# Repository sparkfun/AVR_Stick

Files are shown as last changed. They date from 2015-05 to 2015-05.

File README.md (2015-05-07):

SparkFun AVR Stick
========================================

SparkFun AVR Stick

[*SparkFun AVR Stick (DEV-09147)*](https://www.sparkfun.com/products/9147)

 The SparkFun AVR Stick is a simple data logging device that instantiates itself as an HID keyboard and reports the voltages, along with a ‘timestamp,’ from two pins on an ATtiny85.
 
Repository Contents
-------------------

* **/Firmware** - Example code 
* **/Hardware** - Eagle design files (.brd, .sch)
* **/Production** - Production panel files (.brd)

Documentation
--------------
* **[SparkFun Fritzing repo](https://github.com/sparkfun/Fritzing_Parts)** - Fritzing diagrams for SparkFun products.
* **[SparkFun 3D Model repo](https://github.com/sparkfun/3D_Models)** - 3D models of SparkFun products. 

License Information
-------------------
This product is _**open source**_! 

The **hardware** is released under [Creative Commons ShareAlike 4.0 International](https://creativecommons.org/licenses/by-sa/4.0/).

Please use, reuse, and modify these files as you see fit. Please maintain attribution to SparkFun Electronics and release anything derivative under the same license.

Distributed as-is; no warranty is given.

- Your friends at SparkFun.

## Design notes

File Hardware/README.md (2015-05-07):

SparkFun <PRODUCT NAME> Design Files
=====================================

The .sch and .brd files hare are Eagle CAD schematic and PCB design files from SparkFun Electronics.
A freeware version of Eagle can be found [here](http://www.cadsoftusa.com/download-eagle/freeware/). 

License
---------
This product is open source! 
The hardware is released under [Creative Commons ShareAlike 4.0 International](https://creativecommons.org/licenses/by-sa/4.0/).

Please use, reuse, and modify these files as you see fit. Please maintain attribution to SparkFun Electronics and release anything derivative under the same license.

Distributed as-is; no warranty is given.

- Your friends at SparkFun.

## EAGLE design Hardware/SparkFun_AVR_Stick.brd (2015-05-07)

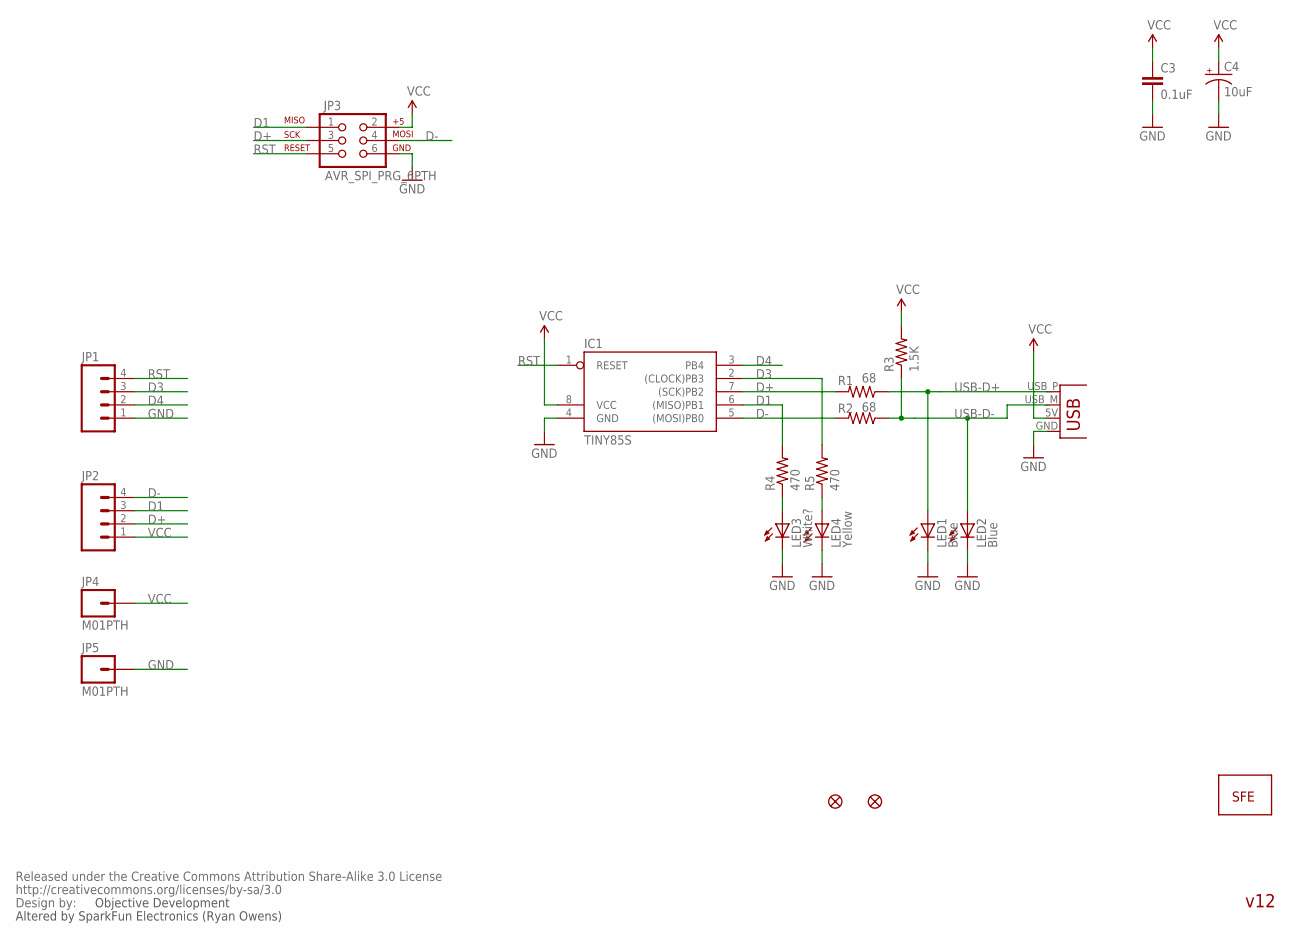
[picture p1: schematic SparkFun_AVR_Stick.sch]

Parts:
C3: 0.1uF; 0402-CAP
C4: 10uF; EIA3216
IC1: TINY85S; SOIC8
JP1, JP2: M04PTH; 1X04
JP3: AVR_SPI_PRG_6PTH; 2X3
JP4, JP5: M01PTH; 1X01
LED1, LED2: Blue; LED-0603
LED3: White?; LED-0603
LED4: Yellow; LED-0603
R1, R2: 68; 0402-RES
R3: 1.5K; 0402-RES
R4, R5: 470; 0402-RES
U$1: LOGO-SFESK; SFE-LOGO-FLAME
U$2, U$3: FIDUCIAL1X2; FIDUCIAL-1X2
U$4: CREATIVE_COMMONS
X1: USBPCB; USB-A-PCB

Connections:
D1: IC1.6 ((MISO)PB1), JP2.3, JP3.1, R4.2
D3: IC1.2 ((CLOCK)PB3), JP1.3, R5.2
D4: IC1.3 (PB4), JP1.2
D+: IC1.7 ((SCK)PB2), JP2.2, JP3.3, R1.2
D-: IC1.5 ((MOSI)PB0), JP2.4, JP3.4, R2.2
GND: C3.2, C4.C (-), IC1.4 (GND), JP1.1, JP3.6, JP5.1, LED1.C, LED2.C, LED3.C, LED4.C, X1.GND
unnamed: LED3.A, R4.1
unnamed: LED4.A, R5.1
RST: IC1.1 (RESET), JP1.4, JP3.5
USB-D+: LED1.A, R1.1, X1.USB_P (D+)
USB-D-: LED2.A, R2.1, R3.1, X1.USB_M (D-)
VCC: C3.1, C4.A (+), IC1.8 (VCC), JP2.1, JP3.2, JP4.1, R3.2, X1.5V (VBUS)

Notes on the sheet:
Objective Development
Altered by SparkFun Electronics (Ryan Owens)
v12

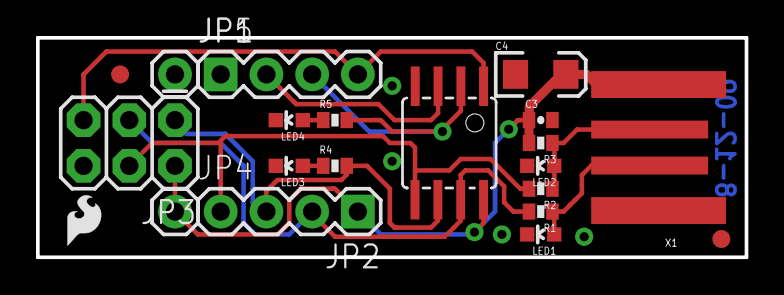
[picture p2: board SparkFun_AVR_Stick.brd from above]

Board: 2 copper layers, 39.4 x 12.2 mm, 22 parts (0 on the bottom side), 12 nets.

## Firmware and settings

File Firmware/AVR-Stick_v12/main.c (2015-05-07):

/* Name: main.c
 * Project: Datalogger based on AVR USB driver
 * Original Author: Christian Starkjohann
 * Edited by Ryan Owens (SparkFun Electronics)
 * Creation Date: 2006-04-23
 * Edited 2009-06-30
 * Tabsize: 4
 * Copyright: (c) 2006 by OBJECTIVE DEVELOPMENT Software GmbH
 * License: Proprietary, free under certain conditions. See Documentation.
 * This Revision: $Id: main.c 537 2008-02-28 21:13:01Z cs $
 */

#include <avr/io.h>
#include <avr/wdt.h>
#include <avr/eeprom.h>
#include <avr/interrupt.h>
#include <avr/pgmspace.h>
#include <util/delay.h>

#include "usbdrv.h"
#include "oddebug.h"

/*
Pin assignment:
PB3 = analog input (ADC3)
PB4 = analog input (ADC2) - Can alternately be used as an LED output.
PB1 = LED output

PB0, PB2 = USB data lines
*/

#define WHITE_LED 3
#define YELLOW_LED 1


#define UTIL_BIN4(x)        (uchar)((0##x & 01000)/64 + (0##x & 0100)/16 + (0##x & 010)/4 + (0##x & 1))
#define UTIL_BIN8(hi, lo)   (uchar)(UTIL_BIN4(hi) * 16 + UTIL_BIN4(lo))

#define sbi(var, mask)   ((var) |= (uint8_t)(1 << mask))
#define cbi(var, mask)   ((var) &= (uint8_t)~(1 << mask))

#ifndef NULL
#define NULL    ((void *)0)
#endif

/* ------------------------------------------------------------------------- */

static uchar    reportBuffer[2];    /* buffer for HID reports */
static uchar    idleRate;           /* in 4 ms units */

static uchar    adcPending;
static uchar	currentAdcChannel=2;
static unsigned int		sampleNum=0;

static uchar    valueBuffer[16];
static uchar    *nextDigit;

/* ------------------------------------------------------------------------- */

PROGMEM char usbHidReportDescriptor[USB_CFG_HID_REPORT_DESCRIPTOR_LENGTH] = { /* USB report descriptor */
    0x05, 0x01,                    // USAGE_PAGE (Generic Desktop)
    0x09, 0x06,                    // USAGE (Keyboard)
    0xa1, 0x01,                    // COLLECTION (Application)
    0x05, 0x07,                    //   USAGE_PAGE (Keyboard)
    0x19, 0xe0,                    //   USAGE_MINIMUM (Keyboard LeftControl)
    0x29, 0xe7,                    //   USAGE_MAXIMUM (Keyboard Right GUI)
    0x15, 0x00,                    //   LOGICAL_MINIMUM (0)
    0x25, 0x01,                    //   LOGICAL_MAXIMUM (1)
    0x75, 0x01,                    //   REPORT_SIZE (1)
    0x95, 0x08,                    //   REPORT_COUNT (8)
    0x81, 0x02,                    //   INPUT (Data,Var,Abs)
    0x95, 0x01,                    //   REPORT_COUNT (1)
    0x75, 0x08,                    //   REPORT_SIZE (8)
    0x25, 0x65,                    //   LOGICAL_MAXIMUM (101)
    0x19, 0x00,                    //   USAGE_MINIMUM (Reserved (no event indicated))
    0x29, 0x65,                    //   USAGE_MAXIMUM (Keyboard Application)
    0x81, 0x00,                    //   INPUT (Data,Ary,Abs)
    0xc0                           // END_COLLECTION
};
/* We use a simplifed keyboard report descriptor which does not support the
 * boot protocol. We don't allow setting status LEDs and we only allow one
 * simultaneous key press (except modifiers). We can therefore use short
 * 2 byte input reports.
 * The report descriptor has been created with usb.org's "HID Descriptor Tool"
 * which can be downloaded from http://www.usb.org/developers/hidpage/.
 * Redundant entries (such as LOGICAL_MINIMUM and USAGE_PAGE) have been omitted
 * for the second INPUT item.
 */

/* Keyboard usage values, see usb.org's HID-usage-tables document, chapter
 * 10 Keyboard/Keypad Page for more codes.
 */
#define MOD_CONTROL_LEFT    (1<<0)
#define MOD_SHIFT_LEFT      (1<<1)
#define MOD_ALT_LEFT        (1<<2)
#define MOD_GUI_LEFT        (1<<3)
#define MOD_CONTROL_RIGHT   (1<<4)
#define MOD_SHIFT_RIGHT     (1<<5)
#define MOD_ALT_RIGHT       (1<<6)
#define MOD_GUI_RIGHT       (1<<7)

#define KEY_1       30
#define KEY_2       31
#define KEY_3       32
#define KEY_4       33
#define KEY_5       34
#define KEY_6       35
#define KEY_7       36
#define KEY_8       37
#define KEY_9       38
#define KEY_0       39
#define KEY_RETURN  40
#define KEY_TAB		43
#define KEY_A		4
#define KEY_B		5
#define KEY_C		6
#define KEY_D		7
#define KEY_E		8
#define KEY_F		9

/* ------------------------------------------------------------------------- */

static void buildReport(void)
{
uchar   key = 0;

    if(nextDigit != NULL){
        key = *nextDigit;
    }
    reportBuffer[0] = 0;    /* no modifiers */
    reportBuffer[1] = key;
}

/* ------------------------------------------------------------------------- */
static void changeAdcChannel(void)
{
	if(currentAdcChannel==3){
		currentAdcChannel=2;
		ADMUX = UTIL_BIN8(1001, 0010);	/* Vref=2.56V, measure ADC2 */
    }
	else{
		currentAdcChannel=3;
		ADMUX = UTIL_BIN8(1001, 0011);  /* Vref=2.56V, measure ADC3 */
	}
}

/* ------------------------------------------------------------------------- */
static void evaluateADC(unsigned int value)
{
uchar   digit;
unsigned int	timestamp;	//Keep track of how many readings we've made so we can add it to the report.

    value += value + (value >> 1);  /* value = value * 2.5 for output in mV */
	
    nextDigit = &valueBuffer[sizeof(valueBuffer)];	//The Buffer is constructed 'backwards,' so point to the end of the Value Buffer before adding the values.
    *--nextDigit = 0xff;/* terminate with 0xff */
    *--nextDigit = 0;
    if(currentAdcChannel==2)*--nextDigit = KEY_TAB;	//We'll seperate the two ADC readings with a 'TAB'
	else *--nextDigit = KEY_RETURN;						//After the second ADC reading, a carriage return character will be sent.
    //Convert the ADC reading to ASCII.
	do{
        digit = value % 10;
        value /= 10;
        *--nextDigit = 0;
        if(digit == 0){
            *--nextDigit = KEY_0;
        }else{
            *--nextDigit = KEY_1 - 1 + digit;
        }
    }while(value != 0);
	
	//Prepend each report with a timetamp.
	if(currentAdcChannel==2){
		timestamp=sampleNum++;
		*--nextDigit = KEY_TAB;
		do{
			digit = timestamp % 10;
			timestamp /= 10;
			*--nextDigit = 0;
			if(digit == 0){
				*--nextDigit = KEY_0;
			}else{
				*--nextDigit = KEY_1 - 1 + digit;
			}
		}while(timestamp != 0);
	}

}

/* ------------------------------------------------------------------------- */

static void adcPoll(void)
{
    if(adcPending && !(ADCSRA & (1 << ADSC))){
		adcPending = 0;
		evaluateADC(ADC);
		changeAdcChannel();
    }
}

/* ------------------------------------------------------------------------- */
static void timerPoll(void)
{
static uchar timerCnt;

    if(TIFR & (1 << TOV1)){	//This flag is triggered at 60 hz.
        TIFR = (1 << TOV1); /* clear overflow */
		if(++timerCnt >= 31){		 /* ~ 0.5 second interval */
            timerCnt = 0;
			adcPending = 1;
			ADCSRA |= (1 << ADSC);  /* start next conversion */
		}
	}
}

/* ------------------------------------------------------------------------- */
static void timerInit(void)
{
    TCCR1 = 0x0b;           /* select clock: 16.5M/1k -> overflow rate = 16.5M/256k = 62.94 Hz */
}

/* ------------------------------------------------------------------------- */
static void adcInit(void)
{
    ADMUX = UTIL_BIN8(1001, 0010);	 /* vref = 2.56V, measure ADC2 (PB4) */
	ADCSRA = UTIL_BIN8(1000, 0111); /* enable ADC, not free running, interrupt disable, rate = 1/128 */
}



/* ------------------------------------------------------------------------- */
/* ------------------------ interface to USB driver ------------------------ */
/* ------------------------------------------------------------------------- */

uchar	usbFunctionSetup(uchar data[8])
{
usbRequest_t    *rq = (void *)data;

    usbMsgPtr = reportBuffer;
    if((rq->bmRequestType & USBRQ_TYPE_MASK) == USBRQ_TYPE_CLASS){    /* class request type */
        if(rq->bRequest == USBRQ_HID_GET_REPORT){  /* wValue: ReportType (highbyte), ReportID (lowbyte) */
            /* we only have one report type, so don't look at wValue */
            buildReport();
            return sizeof(reportBuffer);
        }else if(rq->bRequest == USBRQ_HID_GET_IDLE){
            usbMsgPtr = &idleRate;
            return 1;
        }else if(rq->bRequest == USBRQ_HID_SET_IDLE){
            idleRate = rq->wValue.bytes[1];
        }
    }else{
        /* no vendor specific requests implemented */
    }
	return 0;
}

/* ------------------------------------------------------------------------- */
/* ------------------------ Oscillator Calibration ------------------------- */
/* ------------------------------------------------------------------------- */

/* Calibrate the RC oscillator to 8.25 MHz. The core clock of 16.5 MHz is
 * derived from the 66 MHz peripheral clock by dividing. Our timing reference
 * is the Start Of Frame signal (a single SE0 bit) available immediately after
 * a USB RESET. We first do a binary search for the OSCCAL value and then
 * optimize this value with a neighboorhod search.
 * This algorithm may also be used to calibrate the RC oscillator directly to
 * 12 MHz (no PLL involved, can therefore be used on almost ALL AVRs), but this
 * is wide outside the spec for the OSCCAL value and the required precision for
 * the 12 MHz clock! Use the RC oscillator calibrated to 12 MHz for
 * experimental purposes only!
 */
static void calibrateOscillator(void)
{
uchar       step = 128;
uchar       trialValue = 0, optimumValue;
int         x, optimumDev, targetValue = (unsigned)(1499 * (double)F_CPU / 10.5e6 + 0.5);

    /* do a binary search: */
    do{
        OSCCAL = trialValue + step;
        x = usbMeasureFrameLength();    /* proportional to current real frequency */
        if(x < targetValue)             /* frequency still too low */
            trialValue += step;
        step >>= 1;
    }while(step > 0);
    /* We have a precision of +/- 1 for optimum OSCCAL here */
    /* now do a neighborhood search for optimum value */
    optimumValue = trialValue;
    optimumDev = x; /* this is certainly far away from optimum */
    for(OSCCAL = trialValue - 1; OSCCAL <= trialValue + 1; OSCCAL++){
        x = usbMeasureFrameLength() - targetValue;
        if(x < 0)
            x = -x;
        if(x < optimumDev){
            optimumDev = x;
            optimumValue = OSCCAL;
        }
    }
    OSCCAL = optimumValue;
}
/*
Note: This calibration algorithm may try OSCCAL values of up to 192 even if
the optimum value is far below 192. It may therefore exceed the allowed clock
frequency of the CPU in low voltage designs!
You may replace this search algorithm with any other algorithm you like if
you have additional constraints such as a maximum CPU clock.
For version 5.x RC oscillators (those with a split range of 2x128 steps, e.g.
ATTiny25, ATTiny45, ATTiny85), it may be useful to search for the optimum in
both regions.
*/

void    usbEventResetReady(void)
{
    calibrateOscillator();
    eeprom_write_byte(0, OSCCAL);   /* store the calibrated value in EEPROM */
}

/* ------------------------------------------------------------------------- */
/* --------------------------------- main ---------------------------------- */
/* ------------------------------------------------------------------------- */

int main(void)
{
//uchar   i;
unsigned int i;
uchar   calibrationValue;

    calibrationValue = eeprom_read_byte(0); /* calibration value from last time */
    if(calibrationValue != 0xff){
        OSCCAL = calibrationValue;
    }
    //odDebugInit();
	
	//Production Test Routine - Turn on both LEDs and an LED on the SparkFun Pogo Test Bed.
	DDRB |= 1 << WHITE_LED | 1 << YELLOW_LED | 1<<4;   /* output for LED */
	sbi(PORTB, WHITE_LED);
    for(i=0;i<20;i++){  /* 300 ms disconnect */
        _delay_ms(15);
    }
	cbi(PORTB, WHITE_LED);
	
	sbi(PORTB, YELLOW_LED);
    for(i=0;i<20;i++){  /* 300 ms disconnect */
        _delay_ms(15);
    }
	cbi(PORTB, YELLOW_LED);
	
	sbi(PORTB, 4);
    for(i=0;i<20;i++){  /* 300 ms disconnect */
        _delay_ms(15);
    }	
	cbi(PORTB, 4);
	
	DDRB &= ~(1<<4);
	
	//Initialize the USB Connection with the host computer.
    usbDeviceDisconnect();
    for(i=0;i<20;i++){  /* 300 ms disconnect */
        _delay_ms(15);
    }
    usbDeviceConnect();
    
    wdt_enable(WDTO_1S);
    
	timerInit();	//Create a timer that will trigger a flag at a ~60hz rate 
    adcInit();		//Setup the ADC conversions
    usbInit();		//Initialize USB comm.
    sei();
    for(;;){    /* main event loop */
        wdt_reset();
        usbPoll();	//Check to see if it's time to send a USB packet
        if(usbInterruptIsReady() && nextDigit != NULL){ /* we can send another key */
            buildReport();	//Get the next 'key press' to send to the host. 
            usbSetInterrupt(reportBuffer, sizeof(reportBuffer));
            if(*++nextDigit == 0xff)    /* this was terminator character */
                nextDigit = NULL;
        }
        timerPoll();	//Check timer to see if it's time to start another ADC conversion.
        adcPoll();		//If an ADC conversion was started, get the value and switch to the other ADC channel for the next conversion.
    }
    return 0;
}

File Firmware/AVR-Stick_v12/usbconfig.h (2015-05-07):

/* Name: usbconfig.h
 * Project: AVR USB driver
 * Author: Christian Starkjohann
 * Creation Date: 2007-06-23
 * Tabsize: 4
 * Copyright: (c) 2007 by OBJECTIVE DEVELOPMENT Software GmbH
 * License: GNU GPL v2 (see License.txt) or proprietary (CommercialLicense.txt)
 * This Revision: $Id: usbconfig.h 537 2008-02-28 21:13:01Z cs $
 */

#ifndef __usbconfig_h_included__
#define __usbconfig_h_included__

/* ---------------------------- Hardware Config ---------------------------- */

#define USB_CFG_IOPORTNAME      B
/* This is the port where the USB bus is connected. When you configure it to
 * "B", the registers PORTB, PINB and DDRB will be used.
 */
#define USB_CFG_DMINUS_BIT      0
/* This is the bit number in USB_CFG_IOPORT where the USB D- line is connected.
 * This may be any bit in the port.
 */
#define USB_CFG_DPLUS_BIT       2
/* This is the bit number in USB_CFG_IOPORT where the USB D+ line is connected.
 * This may be any bit in the port. Please note that D+ must also be connected
 * to interrupt pin INT0!
 */
//#define USB_CFG_CLOCK_KHZ       (F_CPU/1000)
#define USB_CFG_CLOCK_KHZ       (16500000/1000)
/* Clock rate of the AVR in MHz. Legal values are 12000, 16000 or 16500.
 * The 16.5 MHz version of the code requires no crystal, it tolerates +/- 1%
 * deviation from the nominal frequency. All other rates require a precision
 * of 2000 ppm and thus a crystal!
 * Default if not specified: 12 MHz
 */

/* ----------------------- Optional Hardware Config ------------------------ */

/* #define USB_CFG_PULLUP_IOPORTNAME   D */
/* If you connect the 1.5k pullup resistor from D- to a port pin instead of
 * V+, you can connect and disconnect the device from firmware by calling
 * the macros usbDeviceConnect() and usbDeviceDisconnect() (see usbdrv.h).
 * This constant defines the port on which the pullup resistor is connected.
 */
/* #define USB_CFG_PULLUP_BIT          4 */
/* This constant defines the bit number in USB_CFG_PULLUP_IOPORT (defined
 * above) where the 1.5k pullup resistor is connected. See description
 * above for details.
 */

/* --------------------------- Functional Range ---------------------------- */

#define USB_CFG_HAVE_INTRIN_ENDPOINT    1
/* Define this to 1 if you want to compile a version with two endpoints: The
 * default control endpoint 0 and an interrupt-in endpoint 1.
 */
#define USB_CFG_HAVE_INTRIN_ENDPOINT3   0
/* Define this to 1 if you want to compile a version with three endpoints: The
 * default control endpoint 0, an interrupt-in endpoint 1 and an interrupt-in
 * endpoint 3. You must also enable endpoint 1 above.
 */
#define USB_CFG_IMPLEMENT_HALT          0
/* Define this to 1 if you also want to implement the ENDPOINT_HALT feature
 * for endpoint 1 (interrupt endpoint). Although you may not need this feature,
 * it is required by the standard. We have made it a config option because it
 * bloats the code considerably.
 */
#define USB_CFG_INTR_POLL_INTERVAL      10
/* If you compile a version with endpoint 1 (interrupt-in), this is the poll
 * interval. The value is in milliseconds and must not be less than 10 ms for
 * low speed devices.
 */
#define USB_CFG_IS_SELF_POWERED         0
/* Define this to 1 if the device has its own power supply. Set it to 0 if the
 * device is powered from the USB bus.
 */
#define USB_CFG_MAX_BUS_POWER           50
/* Set this variable to the maximum USB bus power consumption of your device.
 * The value is in milliamperes. [It will be divided by two since USB
 * communicates power requirements in units of 2 mA.]
 */
#define USB_CFG_IMPLEMENT_FN_WRITE      0
/* Set this to 1 if you want usbFunctionWrite() to be called for control-out
 * transfers. Set it to 0 if you don't need it and want to save a couple of
 * bytes.
 */
#define USB_CFG_IMPLEMENT_FN_READ       0
/* Set this to 1 if you need to send control replies which are generated
 * "on the fly" when usbFunctionRead() is called. If you only want to send
 * data from a static buffer, set it to 0 and return the data from
 * usbFunctionSetup(). This saves a couple of bytes.
 */
#define USB_CFG_IMPLEMENT_FN_WRITEOUT   0
/* Define this to 1 if you want to use interrupt-out (or bulk out) endpoint 1.
 * You must implement the function usbFunctionWriteOut() which receives all
 * interrupt/bulk data sent to endpoint 1.
 */
#define USB_CFG_HAVE_FLOWCONTROL        0
/* Define this to 1 if you want flowcontrol over USB data. See the definition
 * of the macros usbDisableAllRequests() and usbEnableAllRequests() in
 * usbdrv.h.
 */
#ifndef __ASSEMBLER__
extern void usbEventResetReady(void);
#endif
#define USB_RESET_HOOK(isReset)             if(!isReset){usbEventResetReady();}
/* This macro is a hook if you need to know when an USB RESET occurs. It has
 * one parameter which distinguishes between the start of RESET state and its
 * end.
 */
#define USB_CFG_HAVE_MEASURE_FRAME_LENGTH   1
/* define this macro to 1 if you want the function usbMeasureFrameLength()
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

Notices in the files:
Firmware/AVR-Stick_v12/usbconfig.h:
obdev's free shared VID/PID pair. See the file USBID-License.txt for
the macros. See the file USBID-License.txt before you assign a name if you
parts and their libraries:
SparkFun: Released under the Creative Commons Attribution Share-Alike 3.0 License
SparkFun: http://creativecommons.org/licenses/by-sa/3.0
